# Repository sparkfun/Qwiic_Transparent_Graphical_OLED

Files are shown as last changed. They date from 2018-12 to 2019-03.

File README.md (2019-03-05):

SparkFun Transparent Graphical OLED Breakout (Qwiic)
========================================

SparkFun Transparent Graphical OLED Breakout (Qwiic)

[*SparkFun Transparent Graphical OLED Breakout (Qwiic) (15173)*](https://www.sparkfun.com/products/15173)

The future is here! You asked and we delivered - our Qwiic Transparent Graphical OLED Breakout allows you to display custom images on a transparent screen using either SPI or I<sup>2</sup>C connections. 

With Qwiic connectors it's quick (ha ha) and easy to get started with your own images. However, we still have broken out 0.1"-spaced pins in case you prefer to use a breadboard. Brilliantly lit in the dark and still visible by daylight, this OLED sports a display area of 128x64 pixels, 128x56 of which are completely transparent. Control of the OLED is based on our new HyperDisplay library. 

The Arduino sketch required to drive this display requires quite a bit of dynamic memory, meaning that it is not going to fit on a smaller controller like an ATmega328. Any controller with larger RAM should have no problem. In addition, your 3.3v source should be robust enough to supply around 400mA to the display.

Repository Contents
-------------------

* **/Documentation** - Data sheets, additional product information
* **/Hardware** - Eagle design files (.brd, .sch)
* **/Software** - Related software for the <PRODUCT NAME>

Documentation
--------------
* **[Hookup Guide](https://learn.sparkfun.com/tutorials/transparent-graphical-oled-breakout-hookup-guide)** - Basic hookup guide for the Transparent Graphical OLED.
* **[HyperDisplay Library](https://github.com/sparkfun/SparkFun_HyperDisplay)** - Base arduino library for HyperDisplay.
* **[HyperDisplay SSD1309 Arduino Library](https://github.com/sparkfun/HyperDisplay_SSD1309_ArduinoLibrary)** - Standardized library for control of displays using the SSD1309 driver IC.
* **[HyperDisplay Transparent Graphical OLED Library (UG2856KLBAG01)](https://github.com/sparkfun/HyperDisplay_UG2856KLBAG01_ArduinoLibrary)** - Arduino Library specific to this graphical display
* **[SparkFun Fritzing repo](https://github.com/sparkfun/Fritzing_Parts)** - Fritzing diagrams for SparkFun products. 

License Information
-------------------

This product is _**open source**_! 

Please review the LICENSE.md file for license information. 

If you have any questions or concerns on licensing, please contact techsupport@sparkfun.com.

Distributed as-is; no warranty is given.

- Your friends at SparkFun.

_<COLLABORATION CREDIT>_

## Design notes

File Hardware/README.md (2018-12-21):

SparkFun <PRODUCT NAME> Design Files
=====================================

The .sch and .brd files hare are Eagle CAD schematic and PCB design files from SparkFun Electronics.
A freeware version of Eagle can be found [here](http://www.cadsoftusa.com/download-eagle/freeware/).

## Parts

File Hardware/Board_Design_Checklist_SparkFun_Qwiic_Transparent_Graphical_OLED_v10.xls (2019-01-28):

SECTION | CHECK | STATUS | DEPENDANCY | CORRECT ANSWER | USER | USER-ANSWER | COMMENT | WIKI_LINK
Macro | is_revision | 0
Macro | has_pth | 0
Macro | has_i2c | 1
Macro | has_SPI | 1
Macro | has_1x6_ftdi_header | 0
Macro | has_jumpers | 1
Macro | has_leds | 1
Macro | has_vreg | 1
Macro | has_QFN | 0
Macro | has_SS | 0
Macro | has_multi_sheet | 0
Macro | is_kit | 0
Macro | has_serial | 0
Macro | is_4layer | 0
Macro | has_milling | 0
Macro | has_switchorbutton | 0
Macro | has_collaboration | 0
General | Are the part libraries consistent with eagle github repo? |  |  | YES | owen.lyke | YES
Schematic | Is the proper frame with CC attribution used? |  |  | YES | owen.lyke | YES
Schematic | Are all schematic objects inside the frame? |  |  | YES | owen.lyke | YES
Schematic | Is there a SparkFun Logo? |  |  | YES | owen.lyke | YES
Schematic | Is there an OSHW logo? |  |  | YES | owen.lyke | YES
Schematic | Is proper attribution given to the original designer? |  |  | YES | owen.lyke | YES
Schematic | Is "Revised by: " and the reviser's name present? |  | 2 | YES | owen.lyke | *n/a*
Schematic | Are NET labels the correct FLAG type? |  |  | YES | owen.lyke | YES
Schematic | Have all nets been drawn straight out from pin connections at least one grid space? |  |  | YES | owen.lyke | YES
Schematic | Are all net lines 0.006 inch? |  |  | YES | owen.lyke | YES
Schematic | Are there any 4-way junctions? |  |  | NO | owen.lyke | NO
Schematic | Are junction dots used for all 3-wire connections? |  |  | YES | owen.lyke | YES
Schematic | Are the fiducials in the lower right corner? |  |  | YES | owen.lyke | YES
Schematic | Are the standoffs in the lower right corner? |  |  | YES | owen.lyke | YES
Schematic | Are dashed grey lines ('info' eagle layer 97) used to clearly separate different areas? |  |  | YES | owen.lyke | YES
Schematic | Is the version number correct? |  |  | YES | owen.lyke | YES
Schematic | Is the version number included on all sheets? |  | 12 | YES | owen.lyke | *n/a*
Schematic | Do all GND connections use the GND symbol (oriented downward)? |  |  | YES | owen.lyke | YES
Schematic | Do all VCC connections use the VCC symbol (oriented upward)? |  |  | YES | owen.lyke | YES
Schematic | Is the VCC range clearly labeled? |  |  | YES | owen.lyke | YES
Schematic | Are any jumpers labeled clearly by their function and possible settings? |  | 7 | YES | owen.lyke | YES
Schematic | Are any appropriate warnings (voltage conversion, sensitive I/O) labeled? |  |  | YES | owen.lyke | YES
Schematic | Are any notes of two versions of the board in the schematic (3.3V regulator vs 5V regulator)? |  |  | YES | owen.lyke | n/a
Schematic | Do any part names have '/.~' in them? (Multiple sheets) |  | 12 | NO | owen.lyke | *n/a*
Schematic | Have you verified that the BOM in Sparkle is accurate (also checking for PROD_ID, NAME, VALUE, PREFIX)? |  |  | YES | owen.lyke | YES
Schematic | Do any parts have unnecessary values (Eagle has autoset the package as the value)? |  |  | NO | owen.lyke | NO
Schematic | Regarding the voltage regulator, is the input on the LEFT, and the output on the RIGHT? |  | 9 | YES | owen.lyke | n/a
Schematic | Is the I2C address in the schematic? |  | 4 | YES | owen.lyke | YES
Schematic | Is the I2C pin order correct (GND/VCC/SDA/CLK) and did you consider using a Qwiic connector? |  | 4 | YES | owen.lyke | YES |  | https://wiki.sparkfun.com/index.php?title=Eagle_Rules#Pin_Out.2FConnection_Orientation
Schematic | Is the I2C pull-up resistor isolation jumper present? |  | 4 | YES | owen.lyke | YES |  | https://wiki.sparkfun.com/index.php?title=Eagle_Rules#Component_Placement
Schematic | Is the SPI pull-up resistor for Chip Select present? |  | 5 | YES | owen.lyke | YES |  | https://wiki.sparkfun.com/index.php?title=Eagle_Rules#Component_Placement
Schematic | Is the MISO tri-state buffer included? |  | 5 | YES | owen.lyke | n/a |  | https://wiki.sparkfun.com/index.php?title=Eagle_Rules#Component_Placement
Board | If this is a Qwiic board, does it follow the design guidelines for Qwiic boards in the Wiki? |  | 4 | YES | owen.lyke | YES |  | https://wiki.sparkfun.com/index.php?title=Qwiic_Standard
Board | If this board is not branded as a Qwicc board, but contains a Qwiic connector, is the connector labeled with “QWIIC” text silk? |  | 4 |  | owen.lyke | n/a
Board | Are the inner layers on the correct eagle layers? (2 and 15) |  | 15 | YES | owen.lyke | *n/a* |  | https://wiki.sparkfun.com/index.php?title=Eagle_Rules#Board_Creation.2C_Outline
Board | Does your 4 layer board include '1' '2' '3' '4' in the copper of each layer? |  | 15 | YES | owen.lyke | *n/a* |  | https://wiki.sparkfun.com/index.php?title=Eagle_Rules#Board_Creation.2C_Outline
Board | Is the bottom left corner board dimensions at 0,0? |  |  | YES | owen.lyke | YES |  | https://wiki.sparkfun.com/index.php?title=Eagle_Rules#Board_Creation.2C_Outline
Board | Is the board dimension outline correct thickness? (0.008 inch) |  |  | YES | owen.lyke | YES |  | https://wiki.sparkfun.com/index.php?title=Eagle_Rules#Board_Creation.2C_Outline
Board | If this requires very precise dimensions (e.g. USB stick), did you consider GP's tolerances? (dimension=5mils, Vscore=10mils) |  |  |  | owen.lyke | n/a |  | https://wiki.sparkfun.com/index.php?title=Eagle_Rules#Fab_house_Tolerances
Board | Are 0.1 inch headers lined up on 0.1 inch grid? |  |  | YES | owen.lyke | YES |  | https://wiki.sparkfun.com/index.php?title=Eagle_Rules#Board_Creation.2C_Outline
Board | Are opposing 0.1 inch headers spaced to fit into a breadboard? |  |  | YES | owen.lyke | YES |  | https://wiki.sparkfun.com/index.php?title=Eagle_Rules#Board_Creation.2C_Outline
Board | Do all testpoints have a separation of at least 0.1 inch (preferably placed on a 0.05 inch grid)? |  |  | YES | owen.lyke | YES |  | https://wiki.sparkfun.com/index.php?title=Eagle_Rules#Board_Creation.2C_Outline
Board | Does the board have standoffs? |  |  | YES | owen.lyke | YES |  | https://wiki.sparkfun.com/index.php?title=Eagle_Rules#Board_Creation.2C_Outline
Board | Can standoffs/screws be used clear of other parts? |  |  | YES | owen.lyke | YES |  | https://wiki.sparkfun.com/index.php?title=Eagle_Rules#Board_Creation.2C_Outline
Board | Is the FTDI connector accessible (do neighboring parts allow enough space to clear each side)? |  | 6 | YES | owen.lyke | *n/a* |  | https://wiki.sparkfun.com/index.php?title=Eagle_Rules#Pin_Out.2FConnection_Orientation
Board | Is the FTDI connector oriented so the FTDI breakout can be slid on properly (IC side up, header side down)? |  | 6 | YES | owen.lyke | *n/a* |  | https://wiki.sparkfun.com/index.php?title=Eagle_Rules#Pin_Out.2FConnection_Orientation
Board | Are vias tented correctly? |  |  | YES | owen.lyke | YES |  | https://wiki.sparkfun.com/index.php?title=Eagle_Rules#Trace_Routing.2C_Polygon_Pours.2C_and_Vias
Board | If possible, are all overhanging parts on the same edge of the board (this helps with panelization)? |  |  | YES | owen.lyke | n/a |  | https://wiki.sparkfun.com/index.php?title=Eagle_Rules#Pin_Out.2FConnection_Orientation
Board | If this design requires special ordering or production assembly instructions, have the symbols/packages been added with notes? (PCB thickness, humidity sensitivity, etc.) |  |  | YES | owen.lyke | n/a
Board | Are any vias intended to be used as PTH headers (they shouldn't be)? |  |  | NO | owen.lyke | NO |  | https://wiki.sparkfun.com/index.php?title=Eagle_Rules#Trace_Routing.2C_Polygon_Pours.2C_and_Vias
Board | Is the LED color standard followed? (red for power, blue for STAT, green for TX, yellow for RX) |  | 8 | YES | owen.lyke | YES |  | https://wiki.sparkfun.com/index.php?title=Eagle_Rules#Component_Placement
Board | Do parts that need selective solder have a planned nozzle path on layer 48? (valid widths: 0.178", 0,263", 0.354") |  | 11 | YES | owen.lyke | *n/a* |  | https://wiki.sparkfun.com/index.php?title=Eagle_Rules#Selective_Soldering
Board | As best as possible, do all SMD pads have only 1 trace entering the pad? |  |  | YES | owen.lyke | YES |  | https://wiki.sparkfun.com/index.php?title=Eagle_Rules#PCB_Layout
Board | Are there any natural bridges on SMT components? |  |  | NO | owen.lyke | NO |  | https://wiki.sparkfun.com/index.php?title=Eagle_Rules#PCB_Layout
Board | Do V-Scored edges have a 50 mil border free of pads and parts (to prevent cracking on separation)? |  |  | YES | owen.lyke | YES | Close enough
Board | Is the direction of TX/RX serial connections correct? |  | 14 | YES | owen.lyke | *n/a*
Board | Are the TX/RX pins of the FTDI properly connected? |  | 6 | YES | owen.lyke | *n/a*
Board | Is trace routing up to spec? (to/from center-points, straight lines, 45 angles, 'T' intersections, no right angles or acid traps) |  |  | YES | owen.lyke | YES |  | https://wiki.sparkfun.com/index.php?title=Eagle_Rules#PCB_Layout
Board | For thermal considerations, are traces routed away from the component, with symmetrical routing? |  | 10 | YES | owen.lyke | *n/a*
Board | Do all footprints pass 1:1 check? (Applies mostly to new components) |  |  | YES | owen.lyke | n/a
Board | Are all QFN components with 6 or more leads 75 percent pasted on lead pads? (May be contended depending on performance) |  | 10 | YES | owen.lyke | *n/a* |  | https://wiki.sparkfun.com/index.php?title=Eagle_Rules#Footprints.2FPackages
Board | Are center pad cream apertures properly reduced? (50-75% paste is good) |  | 10 | YES | owen.lyke | *n/a* |  | https://wiki.sparkfun.com/index.php?title=Eagle_Rules#Footprints.2FPackages
Board | Is there solder mask between pads on of 11 mil separation and greater? |  |  | YES | owen.lyke | YES |  | https://wiki.sparkfun.com/index.php?title=Eagle_Rules#Fab_house_Tolerances
Board | Is there a correct version number in the copper (aligned properly with the edge of the PCB)? |  |  | YES | owen.lyke | YES
Board | Are there fiducials on both the TOP and BOTTOM of the board? |  |  | YES | owen.lyke | YES
Board | Does it pass DRC with top/bottom keepout layers on? |  |  | YES | owen.lyke | YES | Yes - FAB limit. Q: why would we pay extra for fab limit at gold phoenix when we could use PCBWAY's minimums?
Board | If there are any DRC errors, have they all been approved? |  |  | YES | owen.lyke | YES | Yes - jumpers overlap errors
Board | Are there airwires after ratsnest? |  |  | NO | owen.lyke | NO
Board | Are all KIT PTH parts on the correct side with correct masking (e.g. the TSTOP or BSTOP expose the correct side) |  | 13 | YES | owen.lyke | *n/a*
Documentation | Is there a note for a 4-layer board (on tDOCU)? |  | 15 | YES | owen.lyke | *n/a*
Documentation | Do all packages have NAME and VALUE? |  |  | YES | owen.lyke | YES
Documentation | Is there a note for a board thickness other than 0.63 inch? |  |  |  | owen.lyke | n/a
Documentation | Are measurements included for outer dimension and standoffs (Eagle layer 47)? |  |  | YES | owen.lyke | YES
Documentation | Are the board dimensions on 0.05 inch or 0.01 inch grid? |  |  | YES | owen.lyke | YES
Documentation | Are routed-out areas labeled 'ROUTE OUT' (on dimension)? |  | 16 | YES | owen.lyke | *n/a*
Documentation | Is the CC/Design By included in tDocu? |  |  | YES | owen.lyke | YES
Documentation | Is the designer name included in tDocu? |  |  | YES | owen.lyke | YES
Documentation | Is 'Revised by:' and 'Revisor Name' included in tDocu? |  | 2 | YES | owen.lyke | *n/a*
Silkscreen/Labeling | Is the name of the board on the board? |  |  | YES | owen.lyke | YES |  | https://wiki.sparkfun.com/index.php?title=Eagle_Rules#PCB_Silk
Silkscreen/Labeling | Do all footprints have 0.008 inch silk footprint? |  |  | YES | owen.lyke | YES
Silkscreen/Labeling | Are all LEDs labeled with their purpose? |  | 8 | YES | owen.lyke | YES
Silkscreen/Labeling | Are all PTHs (aka connectors) clearly labeled with their purpose on both sides of the board? |  |  | YES | owen.lyke | YES
Silkscreen/Labeling | Are battery terminals labeled +/- correctly? |  |  | YES | owen.lyke | n/a
Silkscreen/Labeling | Are all jumpers labeled? |  | 7 | YES | owen.lyke | YES
Silkscreen/Labeling | If it is a 3-way jumper, is there a label on each side of the jumper? |  | 7 | YES | owen.lyke | NO | No - I2C disconnect jumper is just labelled 'I2C PU' for space concerns
Silkscreen/Labeling | Are all switches/buttons labeled properly? |  | 17 | YES | owen.lyke | *n/a*
Silkscreen/Labeling | Are active low pins labeled clearly? |  |  | YES | owen.lyke | YES
Silkscreen/Labeling | Are all labels lined up properly? |  |  | YES | owen.lyke | YES
Silkscreen/Labeling | Is all text at least 0.032 inch, 15 percent radio, and vector? |  |  | YES | owen.lyke | n/a | N/A b/c Buzzard
Silkscreen/Labeling | Does the FTDI connector have BLK/GRN labeled correctly? |  | 6 | YES | owen.lyke | *n/a*
Silkscreen/Labeling | Do all components have polarity or pin 1 labeled? |  |  | YES | owen.lyke | YES
Silkscreen/Labeling | Is the polarity label outside of the package for visibility after part population? |  |  | YES | owen.lyke | YES
Silkscreen/Labeling | Are there check labels for different versions of the board (3.3V vs 5V)? |  |  | YES | owen.lyke | n/a
Silkscreen/Labeling | Is the SparkFun Logo on the board? |  |  | YES | owen.lyke | YES
Silkscreen/Labeling | Is the OSHW logo on the board? |  |  | YES | owen.lyke | YES
Silkscreen/Labeling | Is the firmware opensource? If not, did you omit the OSHW Logo? |  | 18 | YES | owen.lyke | *n/a*
Silkscreen/Labeling | Is any silkscreen overlaid on vias? |  |  | NO | owen.lyke | YES
Silkscreen/Labeling | Is there a URL for any kits or unique boards? |  |  |  | owen.lyke | n/a
Special | Are dimension lines properly spaced for V-scoring (lines on a 0.020” center-to-center spacing)? |  |  |  | owen.lyke | YES
Special | On white solder mask pcbs, is there any solder mask between leads on large SMT components? |  |  |  | owen.lyke | n/a
Special | Are axes labeled correctly? |  |  |  | owen.lyke | n/a
Special | Are there warning labels for high voltage areas? |  |  |  | owen.lyke | NO
END | Thanks for flying with us. Have a great day!! |  |  |  | owen.lyke | YES

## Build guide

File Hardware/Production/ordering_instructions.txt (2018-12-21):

panel size, 91x91mm
PCB thickness, 1.6mm
number of layers, 2
soldermask color, Red
silkscreen color, White
oz copper, 1oz
finish, HASL lead free
stencils, top+bottom
pcs per panel, 9

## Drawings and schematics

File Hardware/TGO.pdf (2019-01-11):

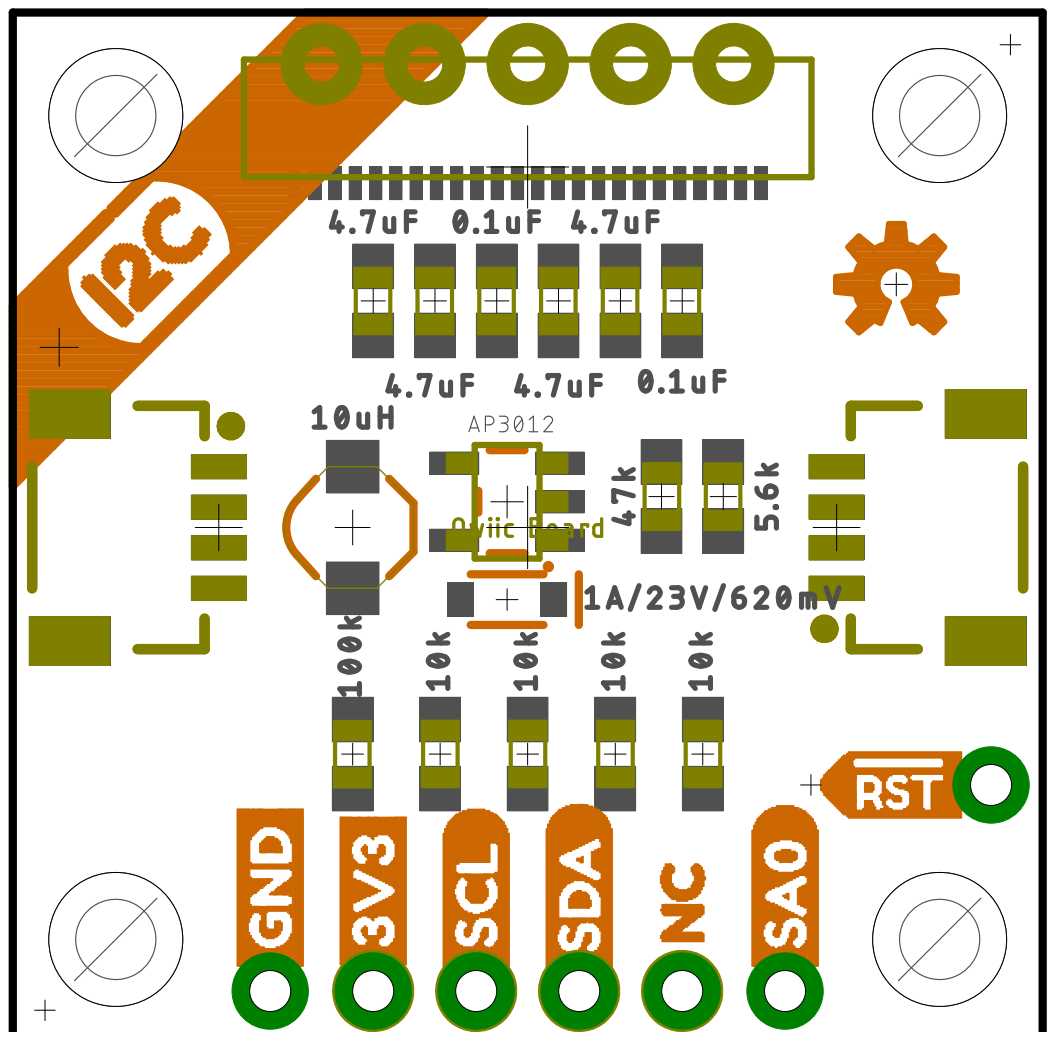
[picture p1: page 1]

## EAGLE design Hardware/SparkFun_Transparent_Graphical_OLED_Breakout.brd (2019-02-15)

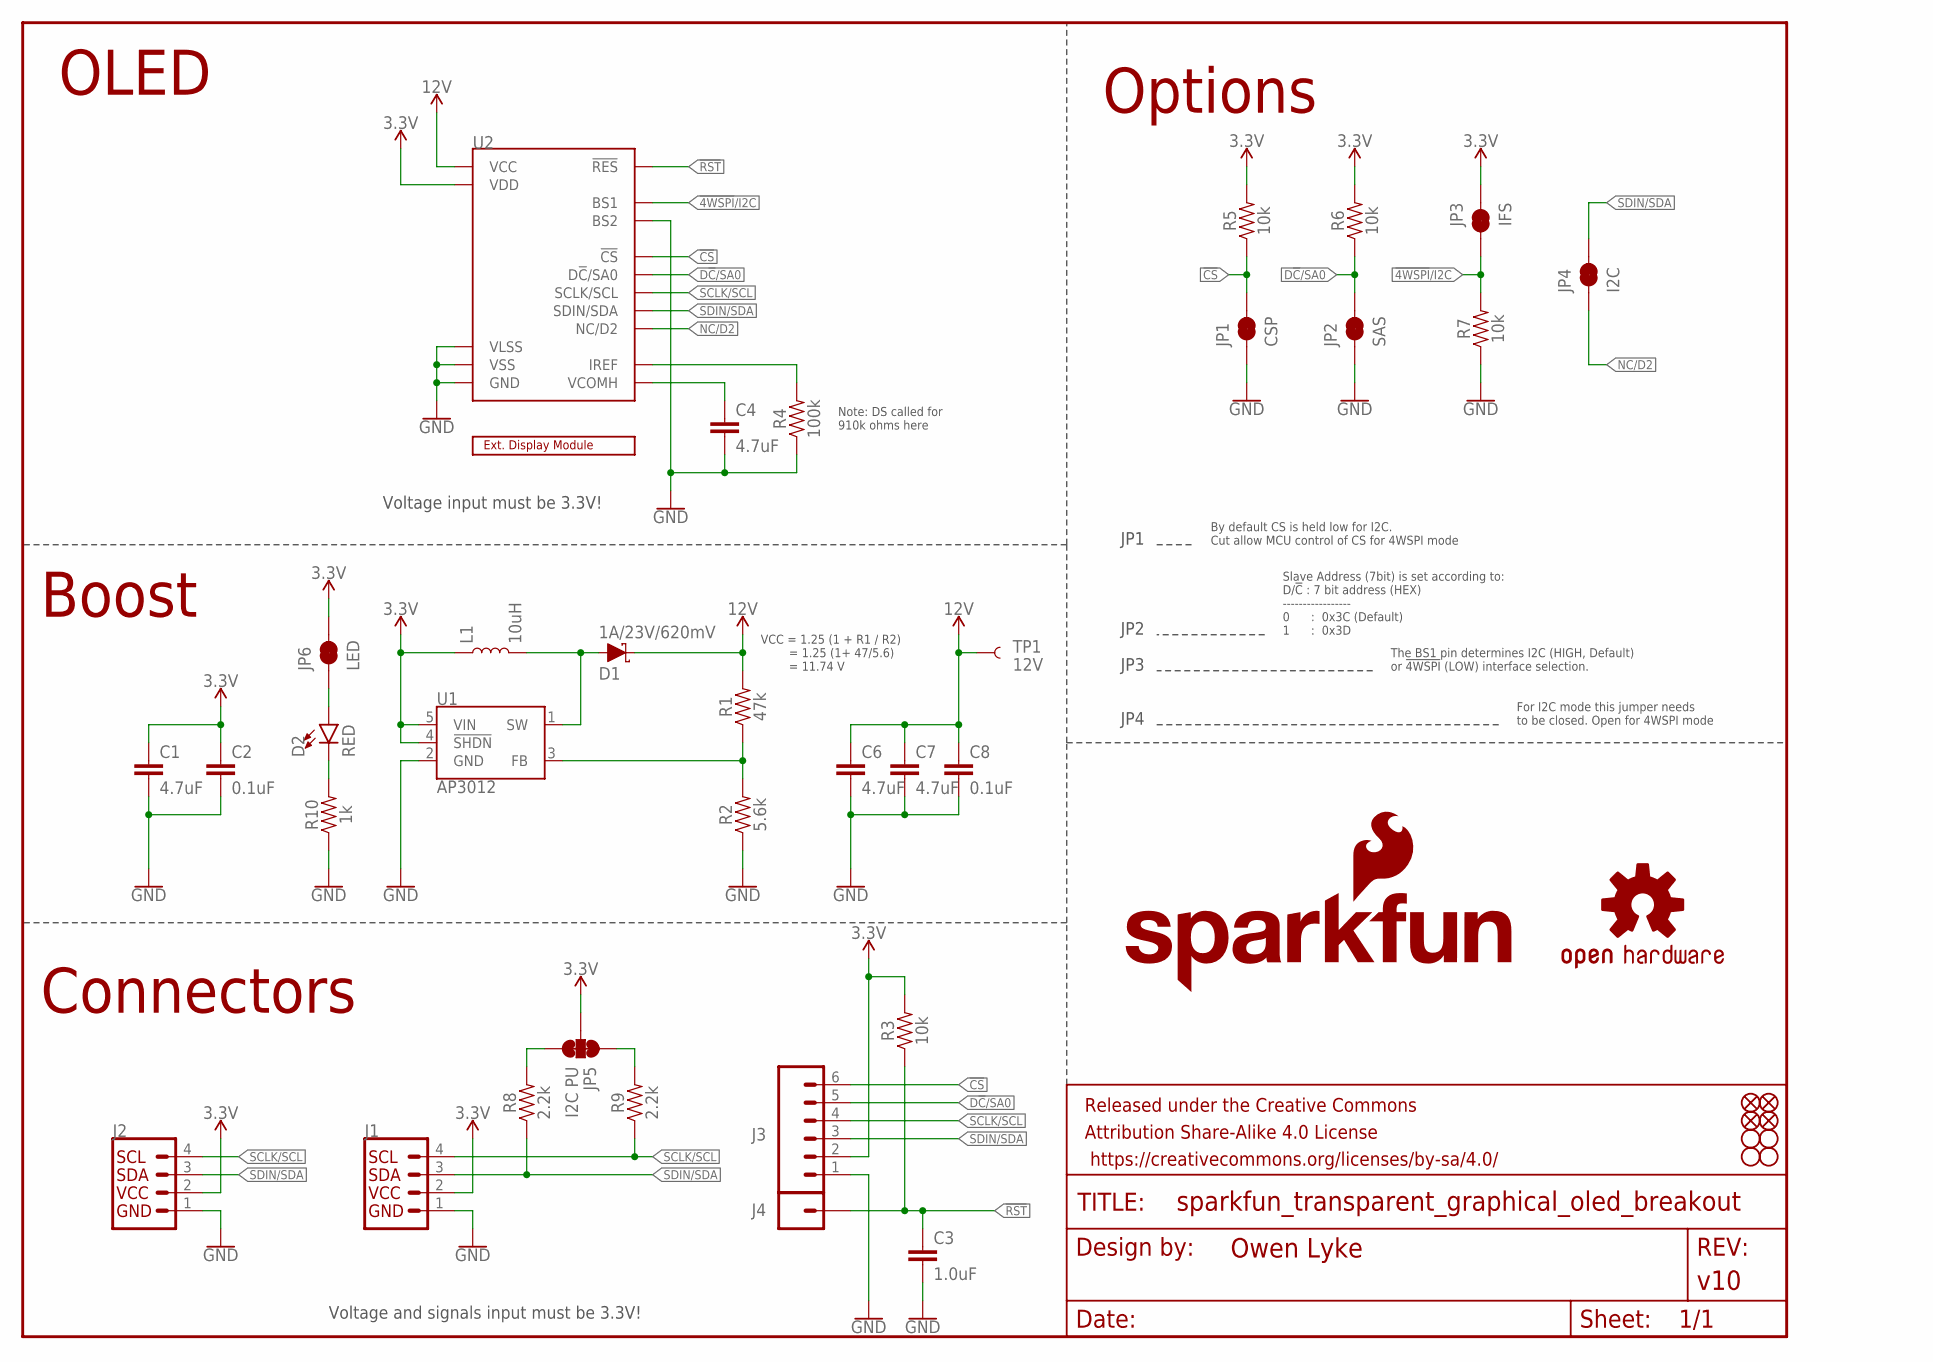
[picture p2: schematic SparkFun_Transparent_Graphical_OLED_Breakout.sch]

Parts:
C1, C4, C6, C7: 4.7uF; 0603
C2, C8: 0.1uF; 0603
C3: 1.0uF; 0603
D1: 1A/23V/620mV; SOD-323
D2: RED; LED-0603
FD1, FD2, FD3, FD4: FIDUCIAL1X2; FIDUCIAL-1X2
FRAME1: FRAME-LETTER; CREATIVE_COMMONS
H1, H2, H3, H4: STAND-OFF
J1, J2: QWIIC_CONNECTORJS-1MM; JST04_1MM_RA
J3: CONN_06NO_SILK_NO_POP; 1X06_NO_SILK
J4: CONN_01PTH_NO_SILK_YES_STOP; 1X01_NO_SILK
JP1: CSP; SMT-JUMPER_2_NC_TRACE_SILK
JP2: SAS; SMT-JUMPER_2_NC_TRACE_SILK
JP3: IFS; SMT-JUMPER_2_NC_TRACE_SILK
JP4: I2C; SMT-JUMPER_2_NC_TRACE_SILK
JP5: I2C PU; SMT-JUMPER_3_2-NC_TRACE_SILK
JP6: LED; SMT-JUMPER_2_NC_TRACE_SILK
L1: 10uH; INDUCTOR_4.7UH
LOGO1: SFE_LOGO_NAME_FLAME.1_INCH; SFE_LOGO_NAME_FLAME_.1
LOGO2: OSHW-LOGOS; OSHW-LOGO-S
R1: 47k; 0603
R2: 5.6k; 0603
R3, R5, R6, R7: 10k; 0603
R4: 100k; 0603
R8, R9: 2.2k; 0603
R10: 1k; 0603
TP1: 12V; PAD.03X.03
U1: AP3012; SOT23-5
U2: UG-2856KLBAG01_4WSPI; FPC05024-42201
U$26: EXTERNAL_DISP-UG-2856KLBAG01; EXT_DISP

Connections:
3.3V: C1.1, C2.1, J1.2, J2.2, J3.2, JP3.1, JP5.2, JP6.2, L1.P$1 (1), R3.2, R5.2, R6.2, U1.4 (!SHDN!), U1.5 (VIN), U2.P$5 (VDD)
12V: C6.1, C7.1, C8.1, D1.C, R1.2, TP1.P$1, U2.P$23 (VCC)
!4WSPI!/I2C: JP3.2, R7.2, U2.P$6 (BS1)
!CS: J3.6, JP1.2, R5.1, U2.P$8 (!CS)
!RST: C3.1, J4.1, R3.1, U2.P$9 (!RES)
D!C!/SA0: J3.5, JP2.2, R6.1, U2.P$10 (D!C!/SA0)
GND: C1.2, C2.2, C3.2, C4.2, C6.2, C7.2, C8.2, J1.1, J2.1, J3.1, JP1.1, JP2.1, R2.1, R4.1, R7.1, R10.1, U1.2 (GND), U2.P$1 (GND), U2.P$2 (VLSS), U2.P$3 (VSS), U2.P$7 (BS2), U2.P$11 (GND), U2.P$12 (GND), U2.P$16 (GND), U2.P$17 (GND), U2.P$18 (GND), U2.P$19 (GND), U2.P$20 (GND), U2.P$24 (GND)
unnamed: R4.2, U2.P$21 (IREF)
unnamed: D2.C, R10.2
unnamed: C4.1, U2.P$22 (VCOMH)
unnamed: D1.A, L1.P$2 (2), U1.1 (SW)
unnamed: R1.1, R2.2, U1.3 (FB)
unnamed: JP5.3, R8.2
unnamed: JP5.1, R9.2
unnamed: D2.A, JP6.1
NC/D2: JP4.1, U2.P$15 (NC/D2)
SCLK/SCL: J1.4, J2.4, J3.4, R9.1, U2.P$13 (SCLK/SCL)
SDIN/SDA: J1.3, J2.3, J3.3, JP4.2, R8.1, U2.P$14 (SDIN/SDA)

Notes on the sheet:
Note: DS called for 910k ohms here
VCC = 1.25 (1 + R1 / R2) = 1.25 (1+ 47/5.6) = 11.74 V
By default CS is held low for I2C. Cut allow MCU control of CS for 4WSPI mode
Slave Address (7bit) is set according to: D/!C! : 7 bit address (HEX) ----------------- 0 : 0x3C (Default) 1 : 0x3D
The BS1 pin determines I2C (HIGH, Default) or !4WSPI! (LOW) interface selection.
For I2C mode this jumper needs to be closed. Open for 4WSPI mode
Connectors
Boost
OLED
Options
Voltage input must be 3.3V!
Voltage and signals input must be 3.3V!
JP1
JP2
JP3
JP4

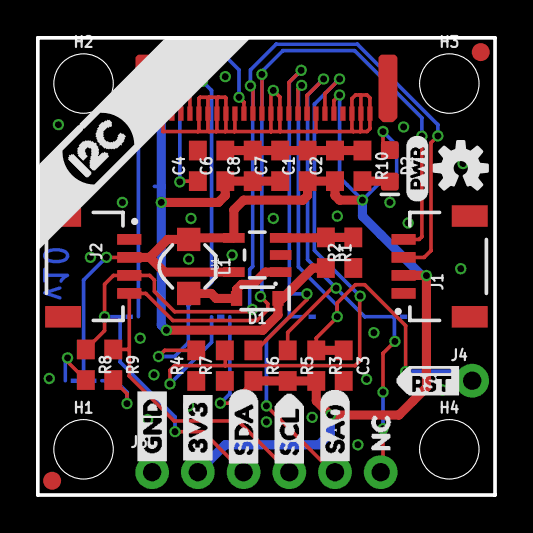
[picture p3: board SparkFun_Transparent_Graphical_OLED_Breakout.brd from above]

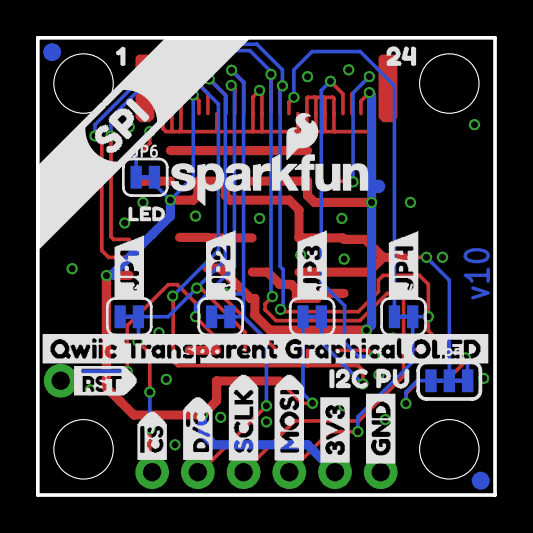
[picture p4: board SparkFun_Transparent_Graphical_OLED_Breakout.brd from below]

Board: 2 copper layers, 25.4 x 25.4 mm, 71 parts (27 on the bottom side), 18 nets.

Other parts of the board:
U$1: JP10
U$2: QWIIC_TRANSPARENT_GRAPHICAL_OLED15
U$3: JP21
U$4, U$14: GND0
U$5, U$13: 3V31
U$6: SCL0
U$7: SDA3
U$8: #CS7
U$9: NC10
U$10: MOSI9
U$11: JP32
U$12: SA08
U$15: D##C6
U$16: JP43
U$17: #RST1
U$18: LED4
U$19: I2C3
U$20: SCLK2
U$21: PWR5
U$22: 17
U$23: 248
U$24: SPI2
U$25: I2C_PU0
U$28: #RST0

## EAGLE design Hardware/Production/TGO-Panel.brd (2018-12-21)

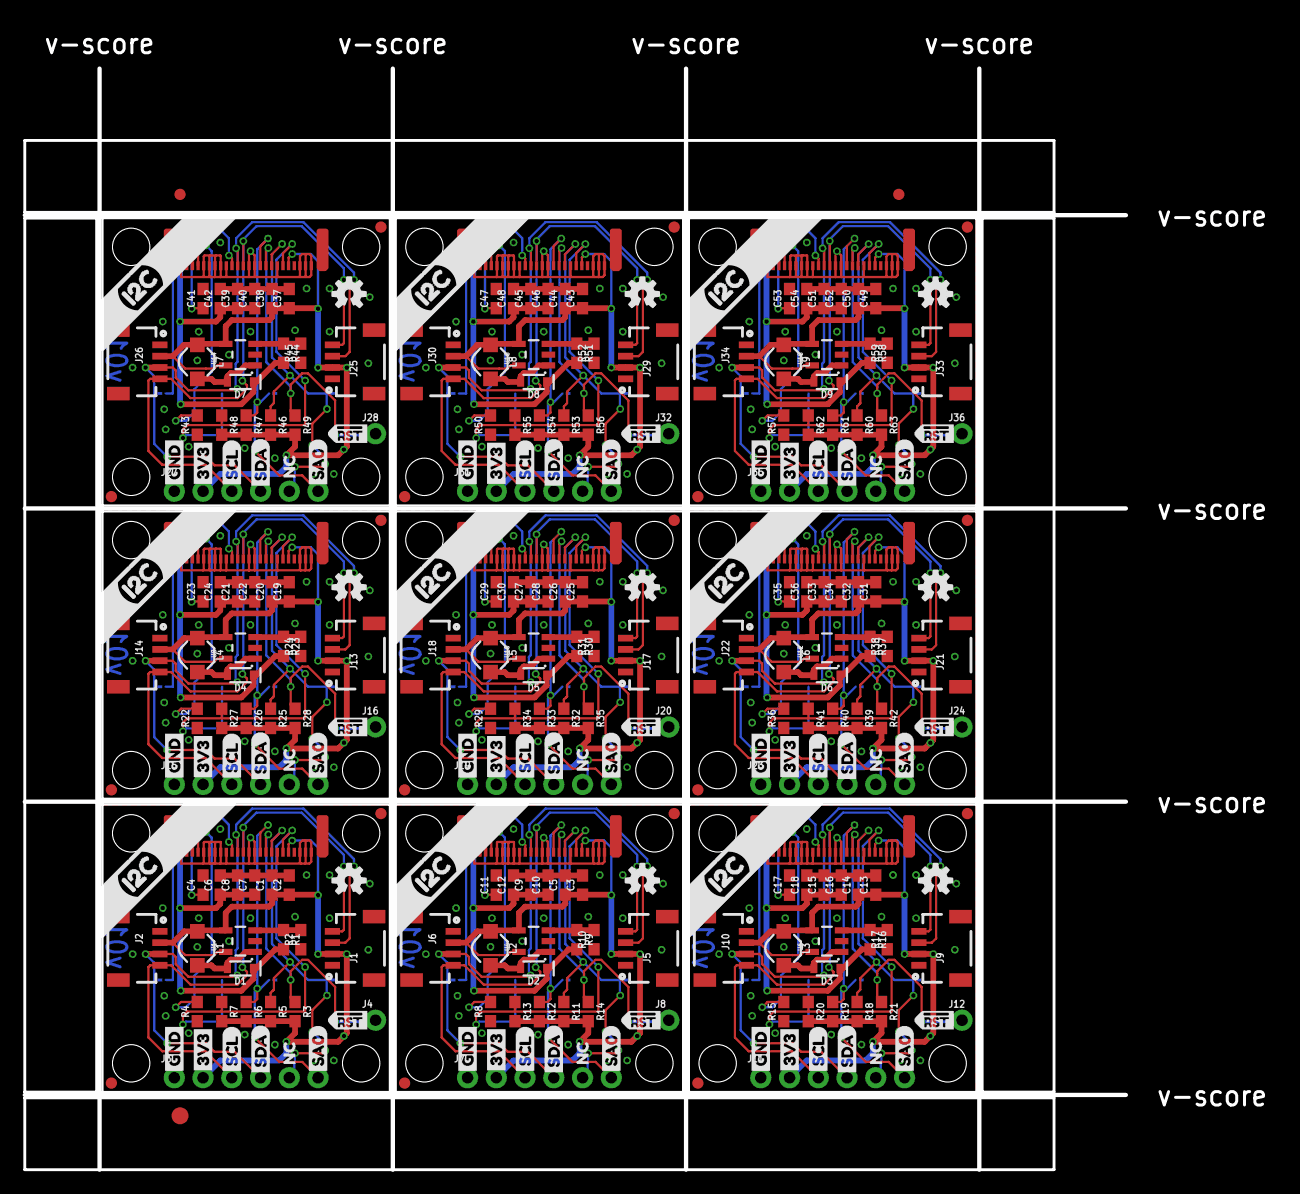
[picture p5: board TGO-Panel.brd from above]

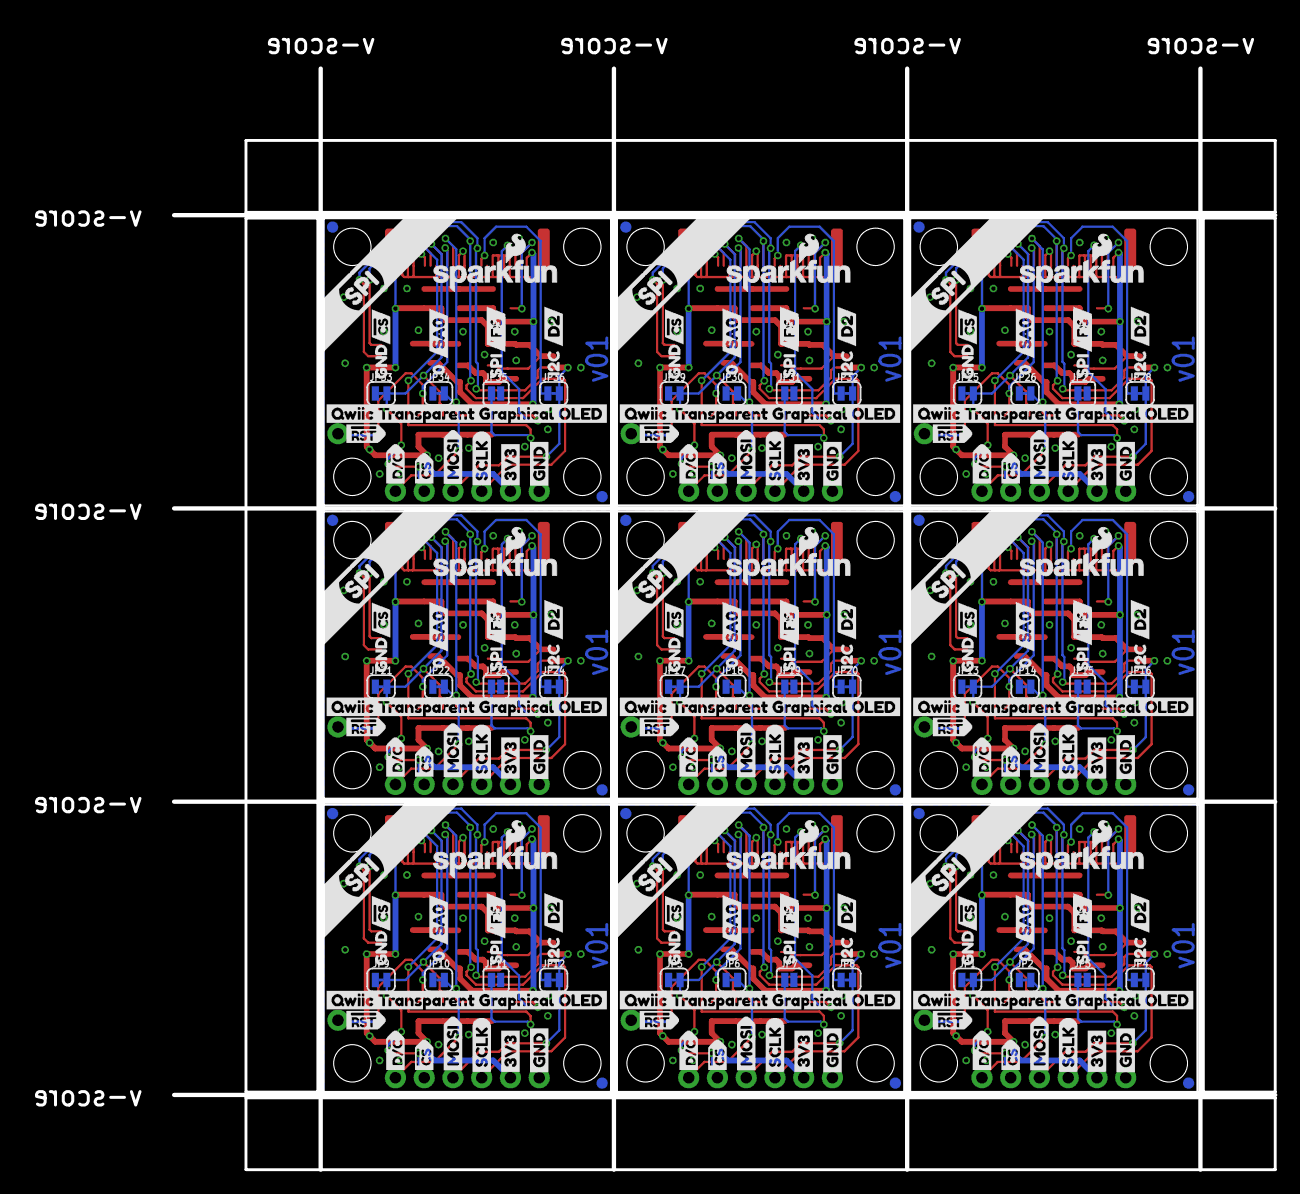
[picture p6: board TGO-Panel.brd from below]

Board: 2 copper layers, 97.3 x 97.3 mm, 525 parts (225 on the bottom side), 126 nets.

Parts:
C1, C4, C5, C6, C7, C10, C11, C12, C14, C16, C17, C18, C20, C22, C23, C24, C26, C28, C29, C30, C32, C34, C35, C36, C38, C40, C41, C42, C44, C46, C47, C48, C50, C52, C53, C54: 4.7uF; 0603
C2, C3, C8, C9, C13, C15, C19, C21, C25, C27, C31, C33, C37, C39, C43, C45, C49, C51: 0.1uF; 0603
D1, D2, D3, D4, D5, D6, D7, D8, D9: 1A/23V/620mV; SOD-323
E$1, E$2: FIDUCIAL-1X2
E$3: FIDUCIAL-1.5X3
FD1, FD2, FD3, FD4, FD5, FD6, FD7, FD8, FD9, FD10, FD11, FD12, FD13, FD14, FD15, FD16, FD17, FD18, FD19, FD20, FD21, FD22, FD23, FD24, FD25, FD26, FD27, FD28, FD29, FD30, FD31, FD32, FD33, FD34, FD35, FD36: FIDUCIAL1X2; FIDUCIAL-1X2
J1, J2, J5, J6, J9, J10, J13, J14, J17, J18, J21, J22, J25, J26, J29, J30, J33, J34: 1X04_1MM_RA
J3, J7, J11, J15, J19, J23, J27, J31, J35: 1X06_NO_SILK
J4, J8, J12, J16, J20, J24, J28, J32, J36: 1X01_NO_SILK
JP1, JP5, JP9, JP13, JP17, JP21, JP25, JP29, JP33: CSP; SMT-JUMPER_2_NC_TRACE_SILK
JP2, JP6, JP10, JP14, JP18, JP22, JP26, JP30, JP34: SAS; SMT-JUMPER_2_NC_TRACE_SILK
JP3, JP7, JP11, JP15, JP19, JP23, JP27, JP31, JP35: IFS; SMT-JUMPER_2_NO_SILK
JP4, JP8, JP12, JP16, JP20, JP24, JP28, JP32, JP36: I2C; SMT-JUMPER_2_NC_TRACE_SILK
L1, L2, L3, L4, L5, L6, L7, L8, L9: 10uH; INDUCTOR_4.7UH
LOGO1, LOGO4, LOGO6, LOGO8, LOGO10, LOGO12, LOGO14, LOGO16, LOGO18: SFE_LOGO_NAME_FLAME.1_INCH; SFE_LOGO_NAME_FLAME_.1
LOGO2, LOGO3, LOGO5, LOGO7, LOGO9, LOGO11, LOGO13, LOGO15, LOGO17: OSHW-LOGOS; OSHW-LOGO-S
R1, R9, R16, R23, R30, R37, R44, R51, R58: 47k; 0603
R2, R10, R17, R24, R31, R38, R45, R52, R59: 5.6k; 0603
R3, R5, R6, R7, R11, R12, R13, R14, R18, R19, R20, R21, R25, R26, R27, R28, R32, R33, R34, R35, R39, R40, R41, R42, R46, R47, R48, R49, R53, R54, R55, R56, R60, R61, R62, R63: 10k; 0603
R4, R8, R15, R22, R29, R36, R43, R50, R57: 100k; 0603
U1, U4, U6, U8, U10, U12, U14, U16, U18: AP3012; SOT23-5
U2, U3, U5, U7, U9, U11, U13, U15, U17: SAS1-1U001-A_I2C_4WSPI; FPC05024-42201
U$1, U$25, U$55, U$82, U$109, U$136, U$163, U$190, U$217: QWIIC_BOARD_OUTLINEH; QWIIC_BOARD_MOUNT_HOLES
U$2, U$44, U$71, U$98, U$125, U$152, U$179, U$206, U$233: QWIIC_TRANSPARENT_GRAPHICAL_OLED15
U$3, U$20, U$53, U$54, U$80, U$81, U$107, U$108, U$134, U$135, U$161, U$162, U$188, U$189, U$215, U$216, U$242, U$243: D27
U$4, U$14, U$27, U$39, U$56, U$66, U$83, U$93, U$110, U$120, U$137, U$147, U$164, U$174, U$191, U$201, U$218, U$228: GND0
U$5, U$13, U$30, U$38, U$57, U$65, U$84, U$92, U$111, U$119, U$138, U$146, U$165, U$173, U$192, U$200, U$219, U$227: 3V31
U$6, U$31, U$58, U$85, U$112, U$139, U$166, U$193, U$220: SCL2
U$7, U$32, U$59, U$86, U$113, U$140, U$167, U$194, U$221: SDA3
U$8, U$35, U$62, U$89, U$116, U$143, U$170, U$197, U$224: #CS7
U$9, U$34, U$61, U$88, U$115, U$142, U$169, U$196, U$223: NC10
U$10, U$36, U$63, U$90, U$117, U$144, U$171, U$198, U$225: MOSI9
U$11, U$37, U$64, U$91, U$118, U$145, U$172, U$199, U$226: SCLK8
U$12, U$33, U$60, U$87, U$114, U$141, U$168, U$195, U$222: SA08
U$15, U$40, U$67, U$94, U$121, U$148, U$175, U$202, U$229: D##C6
U$16, U$41, U$68, U$95, U$122, U$149, U$176, U$203, U$230: GND10
U$17, U$47, U$74, U$101, U$128, U$155, U$182, U$209, U$236: #RST1
U$18, U$42, U$69, U$96, U$123, U$150, U$177, U$204, U$231: 013
U$19, U$48, U$75, U$102, U$129, U$156, U$183, U$210, U$237: I2C3
U$21, U$50, U$77, U$104, U$131, U$158, U$185, U$212, U$239: SA05
U$22, U$43, U$70, U$97, U$124, U$151, U$178, U$205, U$232: I2C13
U$23, U$51, U$78, U$105, U$132, U$159, U$186, U$213, U$240: #CS4
U$24, U$49, U$76, U$103, U$130, U$157, U$184, U$211, U$238: SPI2
U$26, U$45, U$72, U$99, U$126, U$153, U$180, U$207, U$234: IFS17
U$28, U$46, U$73, U$100, U$127, U$154, U$181, U$208, U$235: #RST0
U$29, U$52, U$79, U$106, U$133, U$160, U$187, U$214, U$241: SPI6

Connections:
3.3V: C1.1, C2.1, J1.2, J2.2, J3.2, L1.P$1, R3.2, R5.2, R6.2, R7.2, U1.4, U1.5, U2.P$5
3.3V1: C3.1, C5.1, J5.2, J6.2, J7.2, L2.P$1, R11.2, R12.2, R13.2, R14.2, U3.P$5, U4.4, U4.5
3.3V2: C13.1, C14.1, J9.2, J10.2, J11.2, L3.P$1, R18.2, R19.2, R20.2, R21.2, U5.P$5, U6.4, U6.5
3.3V3: C19.1, C20.1, J13.2, J14.2, J15.2, L4.P$1, R25.2, R26.2, R27.2, R28.2, U7.P$5, U8.4, U8.5
3.3V4: C25.1, C26.1, J17.2, J18.2, J19.2, L5.P$1, R32.2, R33.2, R34.2, R35.2, U9.P$5, U10.4, U10.5
3.3V5: C31.1, C32.1, J21.2, J22.2, J23.2, L6.P$1, R39.2, R40.2, R41.2, R42.2, U11.P$5, U12.4, U12.5
3.3V6: C37.1, C38.1, J25.2, J26.2, J27.2, L7.P$1, R46.2, R47.2, R48.2, R49.2, U13.P$5, U14.4, U14.5
3.3V7: C43.1, C44.1, J29.2, J30.2, J31.2, L8.P$1, R53.2, R54.2, R55.2, R56.2, U15.P$5, U16.4, U16.5
3.3V8: C49.1, C50.1, J33.2, J34.2, J35.2, L9.P$1, R60.2, R61.2, R62.2, R63.2, U17.P$5, U18.4, U18.5
12V: C6.1, C7.1, C8.1, D1.C, R1.2, U2.P$23
12V1: C9.1, C10.1, C12.1, D2.C, R9.2, U3.P$23
12V2: C15.1, C16.1, C18.1, D3.C, R16.2, U5.P$23
12V3: C21.1, C22.1, C24.1, D4.C, R23.2, U7.P$23
12V4: C27.1, C28.1, C30.1, D5.C, R30.2, U9.P$23
12V5: C33.1, C34.1, C36.1, D6.C, R37.2, U11.P$23
12V6: C39.1, C40.1, C42.1, D7.C, R44.2, U13.P$23
12V7: C45.1, C46.1, C48.1, D8.C, R51.2, U15.P$23
12V8: C51.1, C52.1, C54.1, D9.C, R58.2, U17.P$23
!CS: J3.5, JP1.2, R5.1, U2.P$8
!CS1: J7.5, JP5.2, R11.1, U3.P$8
!CS2: J11.5, JP9.2, R18.1, U5.P$8
!CS3: J15.5, JP13.2, R25.1, U7.P$8
!CS4: J19.5, JP17.2, R32.1, U9.P$8
!CS5: J23.5, JP21.2, R39.1, U11.P$8
!CS6: J27.5, JP25.2, R46.1, U13.P$8
!CS7: J31.5, JP29.2, R53.1, U15.P$8
!CS8: J35.5, JP33.2, R60.1, U17.P$8
!RES: J4.1, R3.1, U2.P$9
!RES1: J8.1, R14.1, U3.P$9
!RES2: J12.1, R21.1, U5.P$9
!RES3: J16.1, R28.1, U7.P$9
!RES4: J20.1, R35.1, U9.P$9
!RES5: J24.1, R42.1, U11.P$9
!RES6: J28.1, R49.1, U13.P$9
!RES7: J32.1, R56.1, U15.P$9
!RES8: J36.1, R63.1, U17.P$9
D!C!/SA0: J3.6, JP2.2, R6.1, U2.P$10
D!C!/SA1: J7.6, JP6.2, R12.1, U3.P$10
D!C!/SA2: J11.6, JP10.2, R19.1, U5.P$10
D!C!/SA3: J15.6, JP14.2, R26.1, U7.P$10
D!C!/SA4: J19.6, JP18.2, R33.1, U9.P$10
D!C!/SA5: J23.6, JP22.2, R40.1, U11.P$10
D!C!/SA6: J27.6, JP26.2, R47.1, U13.P$10
D!C!/SA7: J31.6, JP30.2, R54.1, U15.P$10
D!C!/SA8: J35.6, JP34.2, R61.1, U17.P$10
GND: C1.2, C2.2, C4.2, C6.2, C7.2, C8.2, J1.1, J2.1, J3.1, JP1.1, JP2.1, JP3.2, R2.1, R4.1, U1.2, U2.P$1, U2.P$2, U2.P$3, U2.P$7, U2.P$11, U2.P$12, U2.P$16, U2.P$17, U2.P$18, U2.P$19, U2.P$20, U2.P$24
GND1: C3.2, C5.2, C9.2, C10.2, C11.2, C12.2, J5.1, J6.1, J7.1, JP5.1, JP6.1, JP7.2, R8.1, R10.1, U3.P$1, U3.P$2, U3.P$3, U3.P$7, U3.P$11, U3.P$12, U3.P$16, U3.P$17, U3.P$18, U3.P$19, U3.P$20, U3.P$24, U4.2
GND2: C13.2, C14.2, C15.2, C16.2, C17.2, C18.2, J9.1, J10.1, J11.1, JP9.1, JP10.1, JP11.2, R15.1, R17.1, U5.P$1, U5.P$2, U5.P$3, U5.P$7, U5.P$11, U5.P$12, U5.P$16, U5.P$17, U5.P$18, U5.P$19, U5.P$20, U5.P$24, U6.2
GND3: C19.2, C20.2, C21.2, C22.2, C23.2, C24.2, J13.1, J14.1, J15.1, JP13.1, JP14.1, JP15.2, R22.1, R24.1, U7.P$1, U7.P$2, U7.P$3, U7.P$7, U7.P$11, U7.P$12, U7.P$16, U7.P$17, U7.P$18, U7.P$19, U7.P$20, U7.P$24, U8.2
GND4: C25.2, C26.2, C27.2, C28.2, C29.2, C30.2, J17.1, J18.1, J19.1, JP17.1, JP18.1, JP19.2, R29.1, R31.1, U9.P$1, U9.P$2, U9.P$3, U9.P$7, U9.P$11, U9.P$12, U9.P$16, U9.P$17, U9.P$18, U9.P$19, U9.P$20, U9.P$24, U10.2
GND5: C31.2, C32.2, C33.2, C34.2, C35.2, C36.2, J21.1, J22.1, J23.1, JP21.1, JP22.1, JP23.2, R36.1, R38.1, U11.P$1, U11.P$2, U11.P$3, U11.P$7, U11.P$11, U11.P$12, U11.P$16, U11.P$17, U11.P$18, U11.P$19, U11.P$20, U11.P$24, U12.2
GND6: C37.2, C38.2, C39.2, C40.2, C41.2, C42.2, J25.1, J26.1, J27.1, JP25.1, JP26.1, JP27.2, R43.1, R45.1, U13.P$1, U13.P$2, U13.P$3, U13.P$7, U13.P$11, U13.P$12, U13.P$16, U13.P$17, U13.P$18, U13.P$19, U13.P$20, U13.P$24, U14.2
GND7: C43.2, C44.2, C45.2, C46.2, C47.2, C48.2, J29.1, J30.1, J31.1, JP29.1, JP30.1, JP31.2, R50.1, R52.1, U15.P$1, U15.P$2, U15.P$3, U15.P$7, U15.P$11, U15.P$12, U15.P$16, U15.P$17, U15.P$18, U15.P$19, U15.P$20, U15.P$24, U16.2
GND8: C49.2, C50.2, C51.2, C52.2, C53.2, C54.2, J33.1, J34.1, J35.1, JP33.1, JP34.1, JP35.2, R57.1, R59.1, U17.P$1, U17.P$2, U17.P$3, U17.P$7, U17.P$11, U17.P$12, U17.P$16, U17.P$17, U17.P$18, U17.P$19, U17.P$20, U17.P$24, U18.2
I2C!4WSPI: JP3.1, R7.1, U2.P$6
I2C!4WSPI1: JP7.1, R13.1, U3.P$6
I2C!4WSPI2: JP11.1, R20.1, U5.P$6
I2C!4WSPI3: JP15.1, R27.1, U7.P$6
I2C!4WSPI4: JP19.1, R34.1, U9.P$6
I2C!4WSPI5: JP23.1, R41.1, U11.P$6
I2C!4WSPI6: JP27.1, R48.1, U13.P$6
I2C!4WSPI7: JP31.1, R55.1, U15.P$6
I2C!4WSPI8: JP35.1, R62.1, U17.P$6
unnamed: R4.2, U2.P$21
unnamed: C11.1, U3.P$22
unnamed: C4.1, U2.P$22
unnamed: D1.A, L1.P$2, U1.1
unnamed: R1.1, R2.2, U1.3
unnamed: R8.2, U3.P$21
unnamed: D2.A, L2.P$2, U4.1
unnamed: R9.1, R10.2, U4.3
unnamed: C17.1, U5.P$22
unnamed: R15.2, U5.P$21
unnamed: D3.A, L3.P$2, U6.1
unnamed: R16.1, R17.2, U6.3
unnamed: C23.1, U7.P$22
unnamed: R22.2, U7.P$21
unnamed: D4.A, L4.P$2, U8.1
unnamed: R23.1, R24.2, U8.3
unnamed: C29.1, U9.P$22
unnamed: R29.2, U9.P$21
unnamed: D5.A, L5.P$2, U10.1
unnamed: R30.1, R31.2, U10.3
unnamed: C35.1, U11.P$22
unnamed: R36.2, U11.P$21
unnamed: D6.A, L6.P$2, U12.1
unnamed: R37.1, R38.2, U12.3
unnamed: C41.1, U13.P$22
unnamed: R43.2, U13.P$21
unnamed: D7.A, L7.P$2, U14.1
unnamed: R44.1, R45.2, U14.3
unnamed: C47.1, U15.P$22
unnamed: R50.2, U15.P$21
unnamed: D8.A, L8.P$2, U16.1
unnamed: R51.1, R52.2, U16.3
unnamed: C53.1, U17.P$22
unnamed: R57.2, U17.P$21
unnamed: D9.A, L9.P$2, U18.1
unnamed: R58.1, R59.2, U18.3
NC/D1: JP8.1, U3.P$15
NC/D2: JP4.1, U2.P$15
NC/D3: JP12.1, U5.P$15
NC/D4: JP16.1, U7.P$15
NC/D5: JP20.1, U9.P$15
NC/D6: JP24.1, U11.P$15
NC/D7: JP28.1, U13.P$15
NC/D8: JP32.1, U15.P$15
NC/D9: JP36.1, U17.P$15
SCLK/SCL: J1.4, J2.4, J3.3, U2.P$13
SCLK/SCL1: J5.4, J6.4, J7.3, U3.P$13
SCLK/SCL2: J9.4, J10.4, J11.3, U5.P$13
SCLK/SCL3: J13.4, J14.4, J15.3, U7.P$13
SCLK/SCL4: J17.4, J18.4, J19.3, U9.P$13
SCLK/SCL5: J21.4, J22.4, J23.3, U11.P$13
SCLK/SCL6: J25.4, J26.4, J27.3, U13.P$13
SCLK/SCL7: J29.4, J30.4, J31.3, U15.P$13
SCLK/SCL8: J33.4, J34.4, J35.3, U17.P$13
SDIN/SDA: J1.3, J2.3, J3.4, JP4.2, U2.P$14
SDIN/SDA1: J5.3, J6.3, J7.4, JP8.2, U3.P$14
SDIN/SDA2: J9.3, J10.3, J11.4, JP12.2, U5.P$14
SDIN/SDA3: J13.3, J14.3, J15.4, JP16.2, U7.P$14
SDIN/SDA4: J17.3, J18.3, J19.4, JP20.2, U9.P$14
SDIN/SDA5: J21.3, J22.3, J23.4, JP24.2, U11.P$14
SDIN/SDA6: J25.3, J26.3, J27.4, JP28.2, U13.P$14
SDIN/SDA7: J29.3, J30.3, J31.4, JP32.2, U15.P$14
SDIN/SDA8: J33.3, J34.3, J35.4, JP36.2, U17.P$14

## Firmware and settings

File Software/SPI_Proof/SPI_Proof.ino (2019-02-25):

//=-=-=-=-=-=-=-=-=-=-=-=-=-=-=-=-=-=-=-=-=-=-=-=-=-=-=-=-=-=-=-=-=-=-=-=-=-=-=-=-=-=-=-=-=-=-=-=-=-=
//
//  UG-2864KLBMG01 (2864-95E) Reference Code
//
//    Dot Matrix: 128*64
//    Driver IC : SSD1309 (Solomon Systech)
//    Interface : 8-bit 68XX/80XX Parallel, 4-wire USE_SPI
//    Revision  :
//    Date      : 2013/04/09
//    Author    :
//    Editor    : Humphrey Lin
//
//  Copyright (c) WiseChip Semiconductor Inc.
//
//=-=-=-=-=-=-=-=-=-=-=-=-=-=-=-=-=-=-=-=-=-=-=-=-=-=-=-=-=-=-=-=-=-=-=-=-=-=-=-=-=-=-=-=-=-=-=-=-=-=

//#include <at89x51.h>

//#define  M68       // 8-bit 68XX Parallel
            //   BS1=0; BS2=1
// #define    I80       // 8-bit 80XX Parallel
            //   BS1=1; BS2=1
#define USE_SPI       // 4-wire USE_SPI
            //   BS1=0; BS2=0
            //   The unused pins should be connected with VSS mostly or floating (D2).
            //   Please refer to the SSD1309 specification for detail.


////-=-=-=-=-=-=-=-=-=-=-=-=-=-=-=-=-=-=-=-=-=-=-=-=-=-=-=-=-=-=-=-=-=-=-=
////  Pin Definition
////-=-=-=-=-=-=-=-=-=-=-=-=-=-=-=-=-=-=-=-=-=-=-=-=-=-=-=-=-=-=-=-=-=-=-=
//#define xData P1        // Parallel Data Input/Output
//
//#define SCLK  P1_0        // Serial Clock Input
//#define SDIN  P1_1        // Serial Data Input
//
//#define RES P3_3        // Reset
//#define CS  P3_4        // Chip Select
//#define DC  P3_2        // Data/Command Control
//
//#define E P3_0        // Read/Write Enable
//#define RW  P3_1        // Read/Write Select
//
//#define RD  P3_0        // Read Signal
//#define WR  P3_1        // Write Signal

//#define SCLK_PIN 13
//#define SDIN_PIN 11
//#define RES_PIN 3
//#define CS_PIN 4
//#define DC_PIN 5

#include <SPI.h>

#define UG2856KLBAG01_SPI_FREQ_MAX   1000000
#define UG2856KLBAG01_SPI_MODE    SPI_MODE3
#define UG2856KLBAG01_SPI_ORDER   MSBFIRST

#define SCLK_PIN 18
#define SDIN_PIN 23
#define RES_PIN 2
#define CS_PIN 4
#define DC_PIN 5


//-=-=-=-=-=-=-=-=-=-=-=-=-=-=-=-=-=-=-=-=-=-=-=-=-=-=-=-=-=-=-=-=-=-=-=
//  Delay Time
//-=-=-=-=-=-=-=-=-=-=-=-=-=-=-=-=-=-=-=-=-=-=-=-=-=-=-=-=-=-=-=-=-=-=-=
void uDelay(unsigned char l)
{
//  while(l--);
  delayMicroseconds(l);
}


void Delay(unsigned char n)
{
//unsigned char i,j,k;
//
//  for(k=0;k<n;k++)
//  {
//    for(i=0;i<131;i++)
//    {
//      for(j=0;j<15;j++)
//      {
//        uDelay(200);  
//      }
//    }
//  }

  delay(n);

}


//-=-=-=-=-=-=-=-=-=-=-=-=-=-=-=-=-=-=-=-=-=-=-=-=-=-=-=-=-=-=-=-=-=-=-=
//  Read/Write Sequence
//-=-=-=-=-=-=-=-=-=-=-=-=-=-=-=-=-=-=-=-=-=-=-=-=-=-=-=-=-=-=-=-=-=-=-=
#ifdef USE_SPI          // 4-wire USE_SPI
void Write_Command(unsigned char Data)
{
unsigned char i;

  SPI.beginTransaction(SPISettings(UG2856KLBAG01_SPI_FREQ_MAX, UG2856KLBAG01_SPI_ORDER, UG2856KLBAG01_SPI_MODE));

  digitalWrite(CS_PIN, 0);
  digitalWrite(DC_PIN, 0);
//  for (i=0; i<8; i++)
//  {
//    digitalWrite(SCLK_PIN, 0);
//    if((Data&0x80)){ digitalWrite(SDIN_PIN, HIGH); }
//    else{ digitalWrite(SDIN_PIN, LOW); }
//    Data = Data << 1;
//    uDelay(1);
//    digitalWrite(SCLK_PIN, 1);
//    uDelay(1);
//  }
////  digitalWrite(SCLK_PIN, 0);

  SPI.transfer(Data);

  digitalWrite(DC_PIN, 1);
  digitalWrite(CS_PIN, 1);

  SPI.endTransaction();
}


void Write_Data(unsigned char Data)
{
unsigned char i;

  SPI.beginTransaction(SPISettings(UG2856KLBAG01_SPI_FREQ_MAX, UG2856KLBAG01_SPI_ORDER, UG2856KLBAG01_SPI_MODE));

  digitalWrite(CS_PIN, 0);
  digitalWrite(DC_PIN, 1);
//  for (i=0; i<8; i++)
//  {
//    digitalWrite(SCLK_PIN, 0);
//    if((Data&0x80)){ digitalWrite(SDIN_PIN, HIGH); }
//    else{ digitalWrite(SDIN_PIN, LOW); }
//    Data = Data << 1;
//    uDelay(1);
//    digitalWrite(SCLK_PIN, 1);
//    uDelay(1);
//  }
////  digitalWrite(SCLK_PIN, 0);

  SPI.transfer(Data);

  digitalWrite(DC_PIN, 1);
  digitalWrite(CS_PIN, 1);

  SPI.endTransaction();
  
}
#endif


//-=-=-=-=-=-=-=-=-=-=-=-=-=-=-=-=-=-=-=-=-=-=-=-=-=-=-=-=-=-=-=-=-=-=-=
//  Instruction Setting
//-=-=-=-=-=-=-=-=-=-=-=-=-=-=-=-=-=-=-=-=-=-=-=-=-=-=-=-=-=-=-=-=-=-=-=
void Set_Start_Column(unsigned char d)
{
  Write_Command(0x00+d%16);   // Set Lower Column Start Address for Page Addressing Mode
            //   Default => 0x00
  Write_Command(0x10+d/16);   // Set Higher Column Start Address for Page Addressing Mode
            //   Default => 0x10
}


void Set_Addressing_Mode(unsigned char d)
{
  Write_Command(0x20);      // Set Memory Addressing Mode
  Write_Command(d);     //   Default => 0x02
            //     0x00 => Horizontal Addressing Mode
            //     0x01 => Vertical Addressing Mode
            //     0x02 => Page Addressing Mode
}


void Set_Column_Address(unsigned char a, unsigned char b)
{
  Write_Command(0x21);      // Set Column Address
  Write_Command(a);     //   Default => 0x00 (Column Start Address)
  Write_Command(b);     //   Default => 0x7F (Column End Address)
}


void Set_Page_Address(unsigned char a, unsigned char b)
{
  Write_Command(0x22);      // Set Page Address
  Write_Command(a);     //   Default => 0x00 (Page Start Address)
  Write_Command(b);     //   Default => 0x07 (Page End Address)
}


void Set_Start_Line(unsigned char d)
{
  Write_Command(0x40|d);      // Set Display Start Line
            //   Default => 0x40 (0x00)
}


void Set_Contrast_Control(unsigned char d)
{
  Write_Command(0x81);      // Set Contrast Control for Bank 0
  Write_Command(d);     //   Default => 0x7F
}


void Set_Segment_Remap(unsigned char d)
{
  Write_Command(d);     // Set Segment Re-Map
            //   Default => 0xA0
            //     0xA0 => Column Address 0 Mapped to SEG0
            //     0xA1 => Column Address 0 Mapped to SEG127
}


void Set_Entire_Display(unsigned char d)
{
  Write_Command(d);     // Set Entire Display On / Off
            //   Default => 0xA4
            //     0xA4 => Normal Display
            //     0xA5 => Entire Display On
}


void Set_Inverse_Display(unsigned char d)
{
  Write_Command(d);     // Set Inverse Display On/Off
            //   Default => 0xA6
            //     0xA6 => Normal Display
            //     0xA7 => Inverse Display On
}


void Set_Multiplex_Ratio(unsigned char d)
{
  Write_Command(0xA8);      // Set Multiplex Ratio
  Write_Command(d);     //   Default => 0x3F (1/64 Duty)
}


void Set_Display_On_Off(unsigned char d)  
{
  Write_Command(d);     // Set Display On/Off
            //   Default => 0xAE
            //     0xAE => Display Off
            //     0xAF => Display On
}


void Set_Start_Page(unsigned char d)
{
  Write_Command(0xB0|d);      // Set Page Start Address for Page Addressing Mode
            //   Default => 0xB0 (0x00)
}


void Set_Common_Remap(unsigned char d)
{
  Write_Command(d);     // Set COM Output Scan Direction
            //   Default => 0xC0
            //     0xC0 => Scan from COM0 to 63
            //     0xC8 => Scan from COM63 to 0
}


void Set_Display_Offset(unsigned char d)
{
  Write_Command(0xD3);      // Set Display Offset
  Write_Command(d);     //   Default => 0x00
}


void Set_Display_Clock(unsigned char d)
{
  Write_Command(0xD5);      // Set Display Clock Divide Ratio / Oscillator Frequency
  Write_Command(d);     //   Default => 0x70
            //     D[3:0] => Display Clock Divider
            //     D[7:4] => Oscillator Frequency
}


void Set_Low_Power(unsigned char d)
{
  Write_Command(0xD8);      // Set Low Power Display Mode
  Write_Command(d);     //   Default => 0x04 (Normal Power Mode)
}


void Set_Precharge_Period(unsigned char d)
{
  Write_Command(0xD9);      // Set Pre-Charge Period
  Write_Command(d);     //   Default => 0x22 (2 Display Clocks [Phase 2] / 2 Display Clocks [Phase 1])
            //     D[3:0] => Phase 1 Period in 1~15 Display Clocks
            //     D[7:4] => Phase 2 Period in 1~15 Display Clocks
}


void Set_Common_Config(unsigned char d)
{
  Write_Command(0xDA);      // Set COM Pins Hardware Configuration
  Write_Command(d);     //   Default => 0x12
            //     Alternative COM Pin Configuration
            //     Disable COM Left/Right Re-Map
}


void Set_VCOMH(unsigned char d)
{
  Write_Command(0xDB);      // Set VCOMH Deselect Level
  Write_Command(d);     //   Default => 0x34 (0.78*VCC)
}


void Set_NOP()
{
  Write_Command(0xE3);      // Command for No Operation
}


void Set_Command_Lock(unsigned char d)
{
  Write_Command(0xFD);      // Set Command Lock
  Write_Command(d);     //   Default => 0x12
            //     0x12 => Driver IC interface is unlocked from entering command.
            //     0x16 => All Commands are locked except 0xFD.
}


//=-=-=-=-=-=-=-=-=-=-=-=-=-=-=-=-=-=-=-=-=-=-=-=-=-=-=-=-=-=-=-=-=-=-=-=-=-=-=-=
//  Global Variables
//=-=-=-=-=-=-=-=-=-=-=-=-=-=-=-=-=-=-=-=-=-=-=-=-=-=-=-=-=-=-=-=-=-=-=-=-=-=-=-=
#define XLevelL   0x00
#define XLevelH   0x10
#define XLevel    ((XLevelH&0x0F)*16+XLevelL)
#define Max_Column  128
#define Max_Row   64
#define Brightness  0xBF


//=-=-=-=-=-=-=-=-=-=-=-=-=-=-=-=-=-=-=-=-=-=-=-=-=-=-=-=-=-=-=-=-=-=-=-=-=-=-=-=
//  Patterns
//=-=-=-=-=-=-=-=-=-=-=-=-=-=-=-=-=-=-=-=-=-=-=-=-=-=-=-=-=-=-=-=-=-=-=-=-=-=-=-=
unsigned char  UniV[][48]={     // UniV OLED
  0x00,0x00,0xFC,0xFC,0xFC,0xFC,0x00,0x00,0x00,0xFC,0xFC,0xFC,0xFC,0x00,0x00,0x00,0xE0,0xE0,0xE0,0xE0,0x60,0xE0,0xE0,0xE0,0xC0,0x00,0x00,0x00,0xEC,0xEC,0xEC,0xEC,0x00,0x00,0x00,0x04,0x3C,0xFC,0xFC,0xF0,0x80,0x80,0xF0,0xFC,0xFC,0x3C,0x04,0x00,
  0x00,0x00,0x07,0x0F,0x1F,0x1F,0x1C,0x18,0x1C,0x1F,0x1F,0x0F,0x07,0x00,0x00,0x00,0x1F,0x1F,0x1F,0x1F,0x00,0x1F,0x1F,0x1F,0x1F,0x00,0x00,0x00,0x1F,0x1F,0x1F,0x1F,0x00,0x00,0x00,0x00,0x00,0x01,0x0F,0x1F,0x1F,0x1F,0x1F,0x0F,0x01,0x00,0x00,0x00,
  0x00,0x80,0xE0,0xE0,0xF0,0x70,0x30,0x70,0xF0,0xE0,0xE0,0x80,0x00,0x00,0x00,0xF0,0xF0,0xF0,0xF0,0x00,0x00,0x00,0x00,0x00,0x00,0x00,0xF0,0xF0,0xF0,0xF0,0x30,0x30,0x30,0x30,0x30,0x00,0x00,0x00,0xF0,0xF0,0xF0,0xF0,0x30,0x70,0xF0,0xF0,0xE0,0x80,
  0x00,0x0F,0x3F,0x3F,0x7F,0x70,0x60,0x70,0x7F,0x3F,0x3F,0x0F,0x00,0x00,0x00,0x7F,0x7F,0x7F,0x7F,0x60,0x60,0x60,0x60,0x00,0x00,0x00,0x7F,0x7F,0x7F,0x7F,0x63,0x63,0x63,0x63,0x60,0x00,0x00,0x00,0x7F,0x7F,0x7F,0x7F,0x60,0x70,0x7F,0x7F,0x3F,0x0F,
};
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
void loop() {
  // put your main code here, to run repeatedly:


  while(1)
  { 
  // Show Pattern - UniV OLED
    Show_Pattern(&UniV[0][0],0x02,0x05,XLevel+0x28,0x30);
    delay(1000);

  // Fade In/Out (Full Screen)
    Fade_Out();
    Fade_In();
    Fade_Out();
    Fade_In();
    delay(1000);

  // Scrolling (Partial or Full Screen)
    Vertical_Scroll(0x00,0x00,Max_Row,0x01,0x60);
            // Upward - Full Screen
    delay(1000);
    Vertical_Scroll(0x01,0x00,Max_Row,0x01,0x60);
            // Downward - Full Screen
    delay(1000);
    Deactivate_Scroll();
    Continuous_Scroll(0x00,0x00,0x00,0x00,XLevel,XLevel+Max_Column-1,0x00,0x20,0x01,0x00,0x01);
            // Upward - Top Area
    Continuous_Scroll(0x00,0x00,0x00,0x00,XLevel,XLevel+Max_Column-1,0x00,0x20,0x1F,0x00,0x01);
            // Downward - Top Area
    Continuous_Scroll(0x00,0x01,0x00,0x03,XLevel,XLevel+Max_Column-1,0x00,0x20,0x01,0x00,0x02);
            // Up & Rightward - Top Area
    Continuous_Scroll(0x01,0x01,0x00,0x03,XLevel,XLevel+Max_Column-1,0x00,0x20,0x1F,0x00,0x02);
            // Down & Leftward - Top Area
    Continuous_Scroll(0x01,0x01,0x04,0x07,XLevel,XLevel+Max_Column-1,0x00,0x20,0x01,0x00,0x02);
            // Upward - Top Area
            // Leftward - Bottom Area
    Continuous_Scroll(0x00,0x01,0x04,0x07,XLevel,XLevel+Max_Column-1,0x00,0x20,0x1F,0x00,0x02);
            // Downward - Top Area
            // Rightward - Bottom Area
    Deactivate_Scroll();

  // All Pixels On (Test Pattern)
    Fill_RAM(0xFF);
    delay(1000);

  // Checkerboard (Test Pattern)
    Checkerboard();
    delay(1000);
    Fill_RAM(0x00);     // Clear Screen

  // Frame (Test Pattern)
    Frame();
    delay(1000);

  // Show String - WiseChip +886-37-587168
//    Show_String(1,&Name,0x03,XLevel+0x28);
//    Show_String(1,&Tel,0x04,XLevel+0x16);
    Show_String(1,Name,0x03,XLevel+0x28);
    Show_String(1,Tel,0x04,XLevel+0x16);
    delay(1000);
    Fill_RAM(0x00);     // Clear Screen
  }

}

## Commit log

2018-12-21 Finish prototype v01
    [TGO.brd, TGO.sch]
2018-12-21 Proto review changes
    [TGO-Panel.GBL, TGO-Panel.GBO, TGO-Panel.GBS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]
2019-01-11 Move display into SparkFun library
    [TGO.brd, TGO.sch]
2019-01-14 Add pullup resistors on I2C lines, increment version number
    [TGO.brd, TGO.sch]
2019-01-18 Change hardware filenames
    [SparkFun_Transparent_Graphical_OLED_Breakout.brd, SparkFun_Transparent_Graphical_OLED_Breakout.sch]
2019-01-18 Add capacitor to reset line for delayed start up!
    [SparkFun_Transparent_Graphical_OLED_Breakout.brd, SparkFun_Transparent_Graphical_OLED_Breakout.sch]
2019-01-24 Fixed proto issues
    Added I2C pullup resistors and disconnect jumper, added power LED, added reset timing capacitor
    [SparkFun_Transparent_Graphical_OLED_Breakout.brd, SparkFun_Transparent_Graphical_OLED_Breakout.sch]
2019-01-24 Add label for I2C pullup disconnect jumper
    [SparkFun_Transparent_Graphical_OLED_Breakout.brd]
2019-01-24 Tidy schematic
    [SparkFun_Transparent_Graphical_OLED_Breakout.brd, SparkFun_Transparent_Graphical_OLED_Breakout.sch]
2019-01-25 Changed polarity of IFS jumper so that changing to SPI is all cutting, changed silk to match
    [SparkFun_Transparent_Graphical_OLED_Breakout.brd, SparkFun_Transparent_Graphical_OLED_Breakout.sch]
2019-01-25 Notes from reds review added in board
    Yeah its not standard, but it worked
    [SparkFun_Transparent_Graphical_OLED_Breakout.brd, SparkFun_Transparent_Graphical_OLED_Breakout.sch]
2019-01-25 Fixed design review notes
    Jumper labels simplified
    FPC polarity markers added
    version number updated
    I2C resistors moved
    test point added for 12V
    LED disconnect jumper added
    [SparkFun_Transparent_Graphical_OLED_Breakout.brd, SparkFun_Transparent_Graphical_OLED_Breakout.sch]
2019-01-28 Minor changes from Checklist run-through
    [Board_Design_Checklist_SparkFun_Qwiic_Transparent_Graphical_OLED_v10.xls, SparkFun_Transparent_Graphical_OLED_Breakout.brd, SparkFun_Transparent_Graphical_OLED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]
2019-01-29 Fix issue #2
    Added units to measures
    Removed unused via on 3.3V line (lower right)
    Widened input 3.3V trace to boost IC to 20 mil
    [SparkFun_Transparent_Graphical_OLED_Breakout.brd]
2019-01-31 Fix default label of I2C address in schematic
    [SparkFun_Transparent_Graphical_OLED_Breakout.brd, SparkFun_Transparent_Graphical_OLED_Breakout.sch]
2019-02-15 Add External Display Indicator to help avoid BOM issues
    [SparkFun_Transparent_Graphical_OLED_Breakout.brd, SparkFun_Transparent_Graphical_OLED_Breakout.sch]
2019-02-15 Add external display indicator to avoid BOM issues
    [SparkFun_Transparent_Graphical_OLED_Breakout.brd, SparkFun_Transparent_Graphical_OLED_Breakout.sch]
2019-02-25 Make SPI proof use Arduino SPI library

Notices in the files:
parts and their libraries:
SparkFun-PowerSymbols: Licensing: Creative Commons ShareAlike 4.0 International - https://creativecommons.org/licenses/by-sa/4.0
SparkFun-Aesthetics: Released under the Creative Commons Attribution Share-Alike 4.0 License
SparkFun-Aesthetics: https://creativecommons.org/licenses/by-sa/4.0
